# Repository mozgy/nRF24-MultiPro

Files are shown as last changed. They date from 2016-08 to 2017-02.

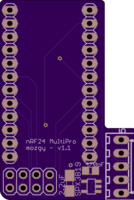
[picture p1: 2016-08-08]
nrf24-top.png

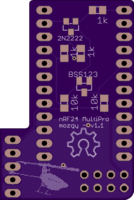
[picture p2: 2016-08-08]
nrf24-bottom.png

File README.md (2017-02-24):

# nRF24-MultiPro
nRF24 MultiPro

Adapter for nRF24 board and Arduino Pro Mini.
Firmware is at https://github.com/goebish/nrf24_multipro

# BOM
Qty|Part|Description|Value|Package|RS Part Number
---|----|-----------|-----|-------|-------------------
1|IC1|Voltage Regulator 3.3V|SPX3819 3.3|SOT23-5|
1|Q1|MOSFET|BSS123|SOT-23|
1|Q2|BJT|2N2222|SOT-23|
1|C1|Cap Tantalum|2.2uF/16V|3216|
2|R1,R2|SMD Resistor|10k|0805|
3|R3,R4,R5|SMD Resistor|1k|0805|
1|JP1|Pin Header|2x4|
2|JP2,JP3|Pin Header|1x12|
1|JP4|Molex Connector|1x5|

(C1 '+' cap markings are towards outter edge of the PCB)

Special thanks to excellent video by Jason Sanctuary - https://www.youtube.com/watch?v=gJYiDjo5lQw

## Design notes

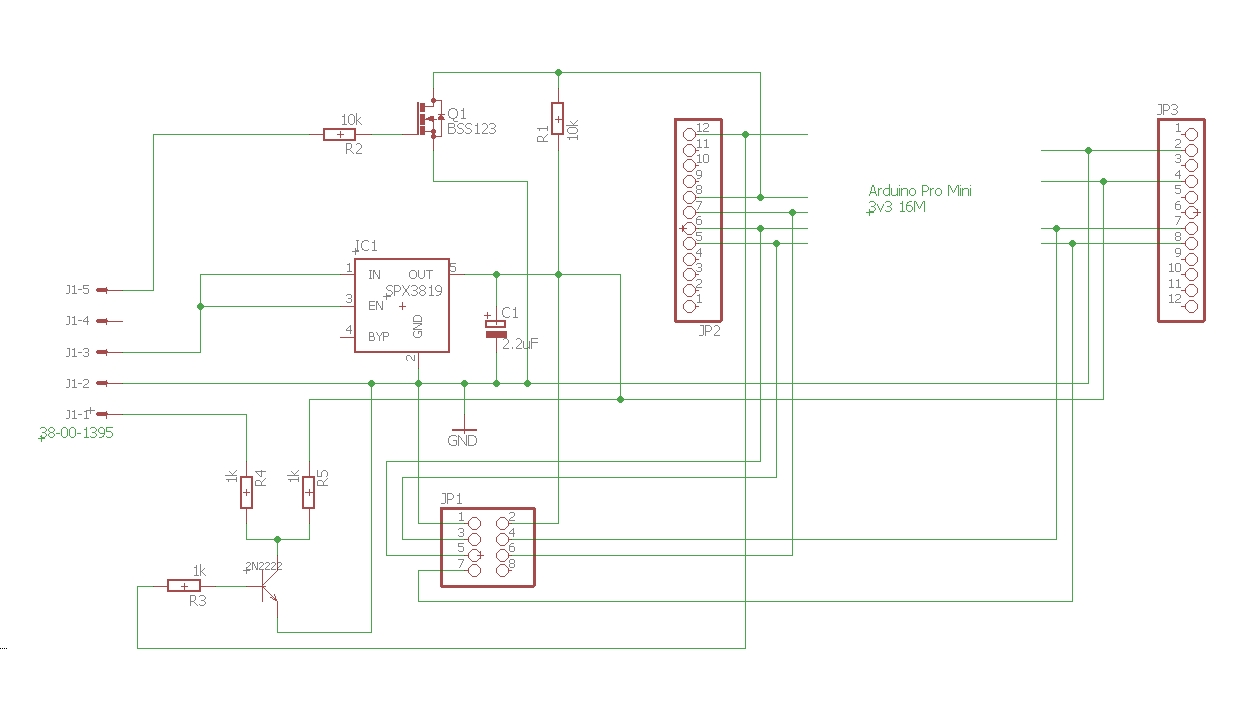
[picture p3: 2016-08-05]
nRF24_MultiPro.jpg

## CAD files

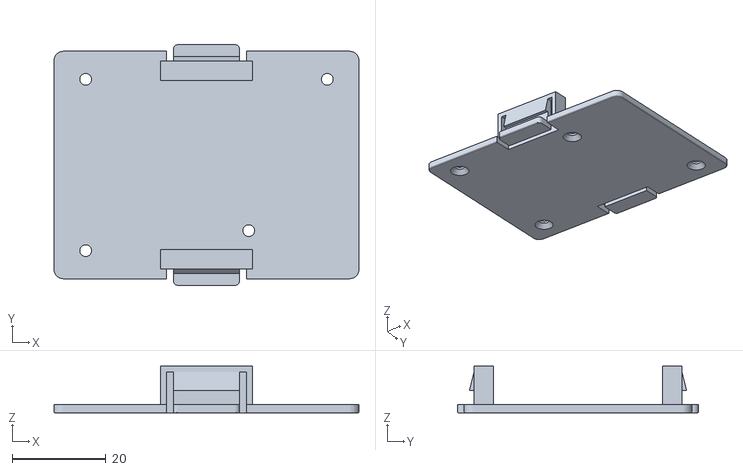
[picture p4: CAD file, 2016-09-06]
nrf24box-lid.stl
65.0 x 51.3 x 10.0

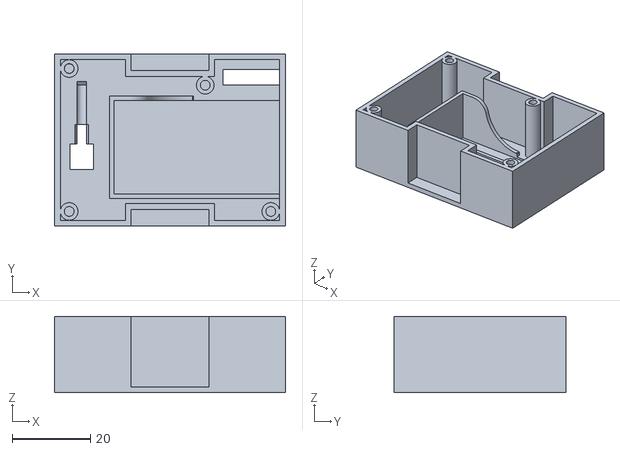
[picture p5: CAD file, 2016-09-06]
nrf24box-box.stl
59.0 x 44.0 x 19.5

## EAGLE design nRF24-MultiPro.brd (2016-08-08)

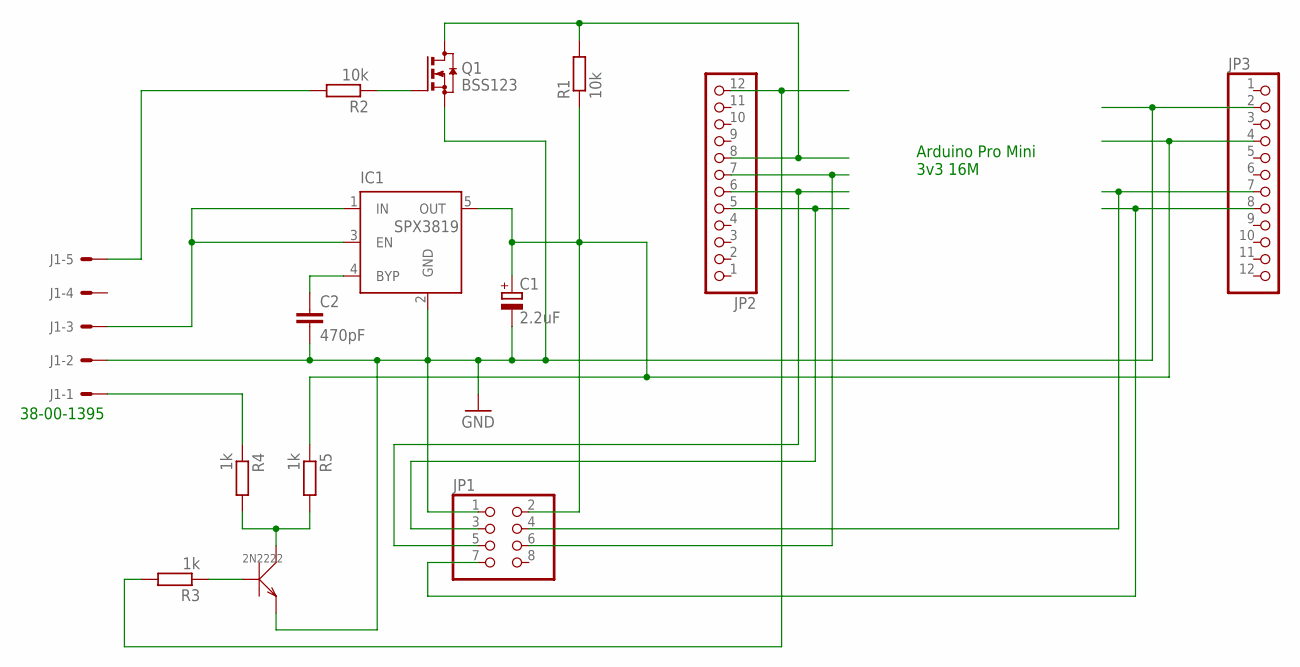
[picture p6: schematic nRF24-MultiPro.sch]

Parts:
2N2222: TRANSISTOR-NPN; SOT-23
C1: 2.2uF; A/3216-18W
C2: 470pF; C0805
IC1: SPX3819; SOT23-5
J1: 22-27-2051-05; 6410-05
JP1: PINHD-2X4; 2X04
JP2, JP3: PINHD-1X12; 1X12
Q1: BSS123; SOT23
R1, R2: 10k; R0805
R3, R4, R5: 1k; R0805

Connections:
GND: 2N2222.2 (E), C1.-, C2.2, IC1.2 (GND), J1.2, JP1.1, JP3.2, Q1.2 (S)
unnamed: IC1.1 (IN), IC1.3 (EN), J1.3
unnamed: JP2.8, Q1.3 (D), R1.2
unnamed: JP1.4, JP3.7
unnamed: C1.+, IC1.5 (OUT), JP1.2, JP3.4, R1.1, R5.1
unnamed: JP1.6, JP2.7
unnamed: 2N2222.1 (B), R3.1
unnamed: Q1.1 (G), R2.1
unnamed: J1.5, R2.2
unnamed: JP1.3, JP2.5
unnamed: JP1.5, JP2.6
unnamed: JP1.7, JP3.8
unnamed: 2N2222.3 (C), R4.2, R5.2
unnamed: J1.1, R4.1
unnamed: C2.1, IC1.4 (BYP)
unnamed: JP2.12, R3.2

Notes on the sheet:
Arduino Pro Mini 3v3 16M
38-00-1395

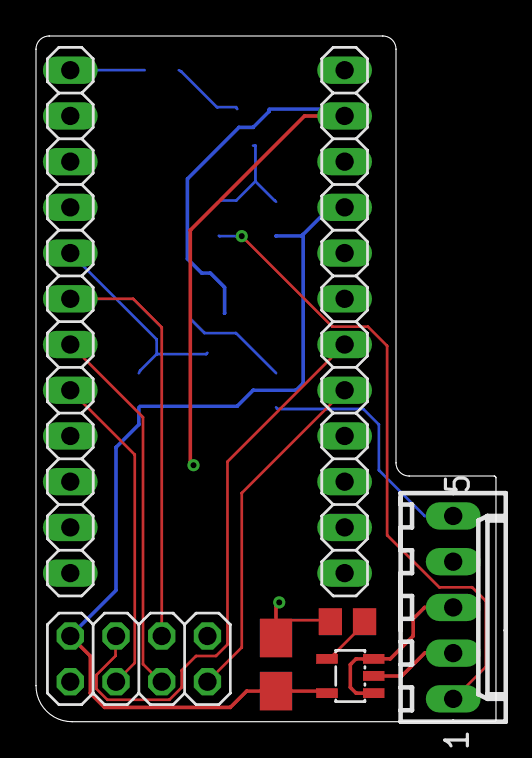
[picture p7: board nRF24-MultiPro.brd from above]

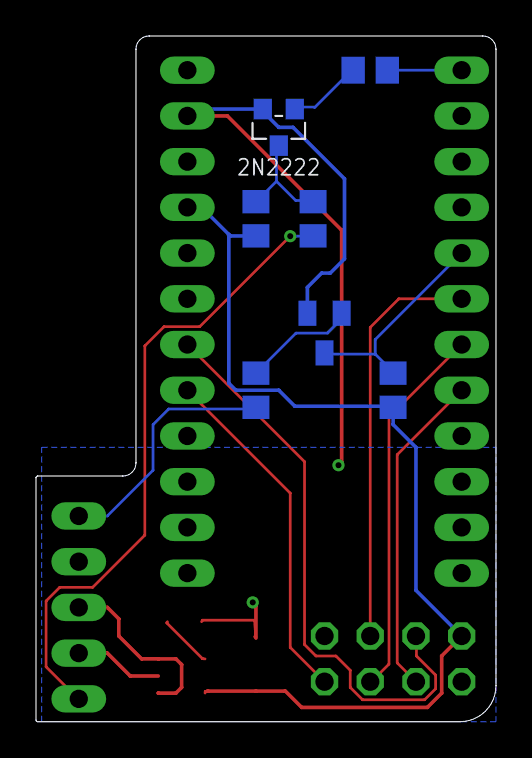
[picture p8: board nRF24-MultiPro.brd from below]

Board: 2 copper layers, 25.6 x 38.1 mm, 14 parts (7 on the bottom side), 16 nets.

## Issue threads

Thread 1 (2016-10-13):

Digikey shopping cart

stratosonic, 2016-10-13:
Here is a digikey shopping cart with the parts needed to complete the board. It might be a good idea to add this to the readme: http://www.digikey.com/short/3927w8

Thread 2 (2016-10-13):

Capacitor C1 missing the mounting direction on the board

stratosonic, 2016-10-13:
There is no indication on the board which way to mount capacitor C1.

mozgy, 2016-10-30:
Actually there is but it is hardly noticeable. Gonna add some additional instructions for that part.
Ty.

Closed 2016-10-30.

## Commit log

2016-08-05 nRF24 MultiPro
    Adapter schematics for nRF24 board and Arduino Pro Mini, firmware at
    https://github.com/goebish/nrf24_multipro
    [nRF24-MultiPro.brd, nRF24-MultiPro.sch]
2016-08-05 Schematics Picture
2016-08-08 OSH Park PCB
    OSH Park PCB
2016-08-08 v1.1 pcb
    - 470pF for low noise
    - slightly rearanged SMDs
    - manualy traced some wires
    - GND and VCC upped to 8mil
    - added logo
    [nRF24-MultiPro.brd, nRF24-MultiPro.sch]
2016-09-06 3D Printer Data
    STLs for 3d printed box, 9xR version with antenae hole.
    [nrf24box-box.stl, nrf24box-lid.stl]
2017-02-24 BOM
    Added BOM
